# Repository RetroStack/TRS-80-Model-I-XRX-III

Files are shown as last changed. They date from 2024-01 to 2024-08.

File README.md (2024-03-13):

# TRS-80 Model 1 XRX-III Mod

This project faithfully reimplements the small brown mod board often seen attached to the keyboard of an TRS-80 Model 1. It corrects a software bug in earlier versions of the Level II ROMs, a bug later fixed in version 1.3. The design replicates the original mod's functionality using a 1-to-1 PCB design, including components, interfaces, and even traces.

Since this mod is no longer required for the latest ROM version, there's no need to create it. If you have an older computer, simply update the ROMs, and this mod becomes unnecessary. This repository serves more as a historical record and recreation of the board rather than for implementation.

For more details about this mod, visit: http://www.trs-80.org/xrx-modification/

The entire project is available under the MIT license.

## Project Details

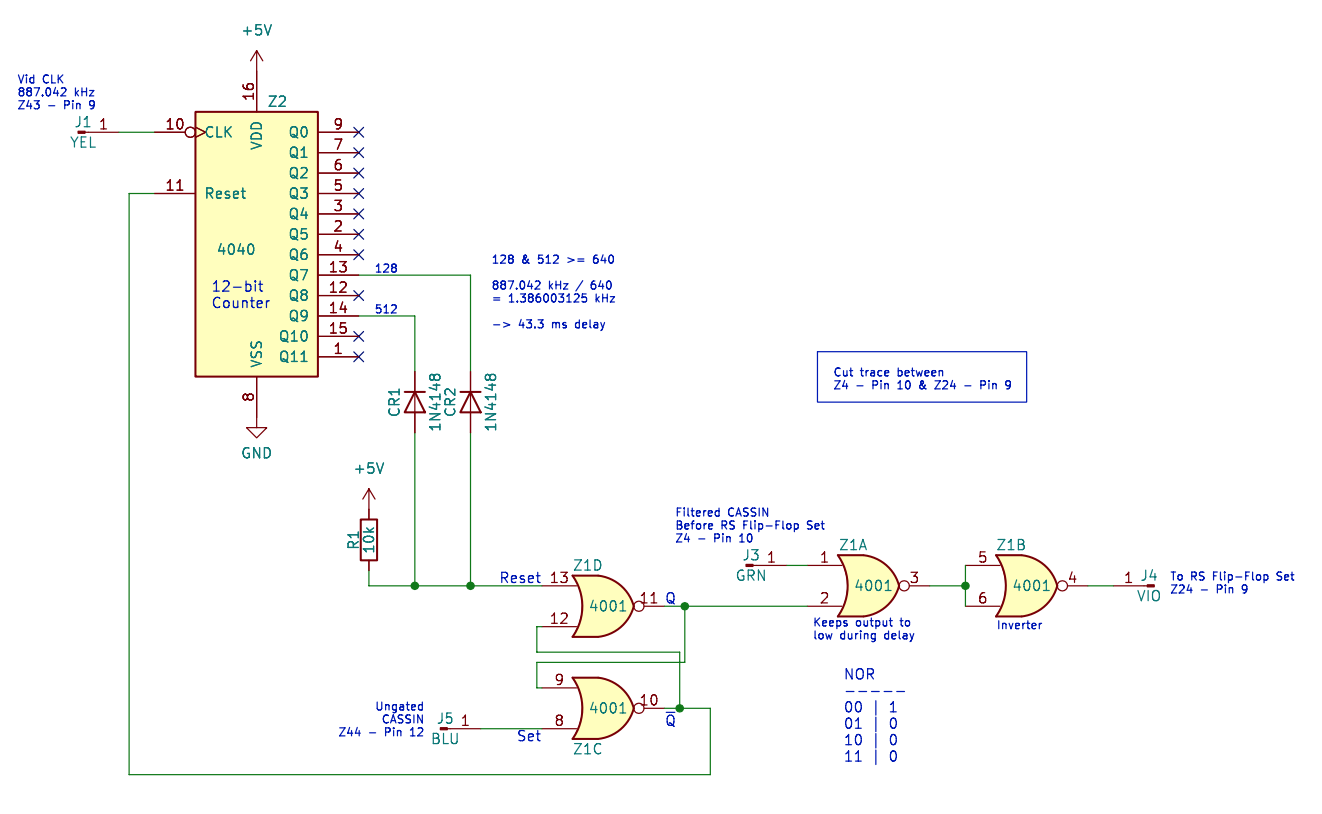
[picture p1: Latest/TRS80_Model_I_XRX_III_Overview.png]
Overview


### Latest Files

In the "Latest" folder, you'll find the most up-to-date design files, including:
- 3D views of the board
- The full schematics

### Implementation

This board has been implemented using KiCAD 7. The KiCAD project files are included in this repository.

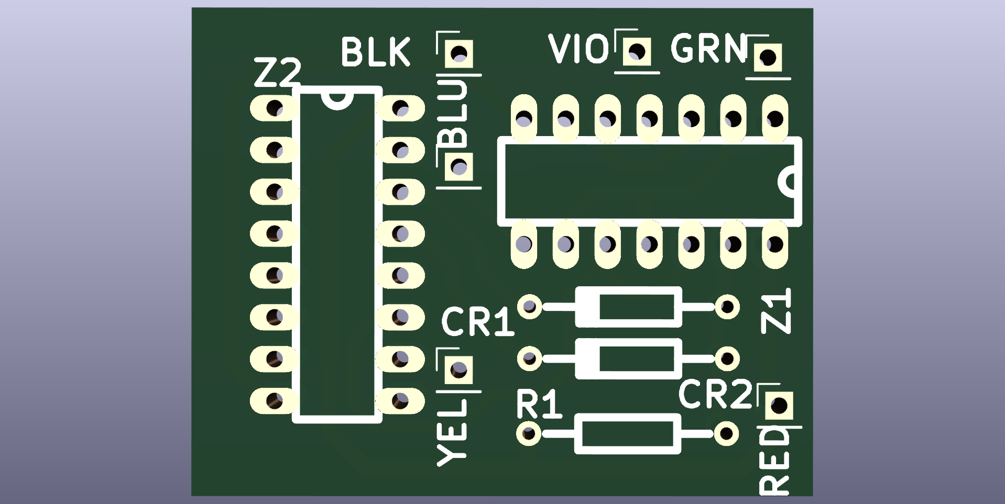
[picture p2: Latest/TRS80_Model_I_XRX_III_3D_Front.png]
Front

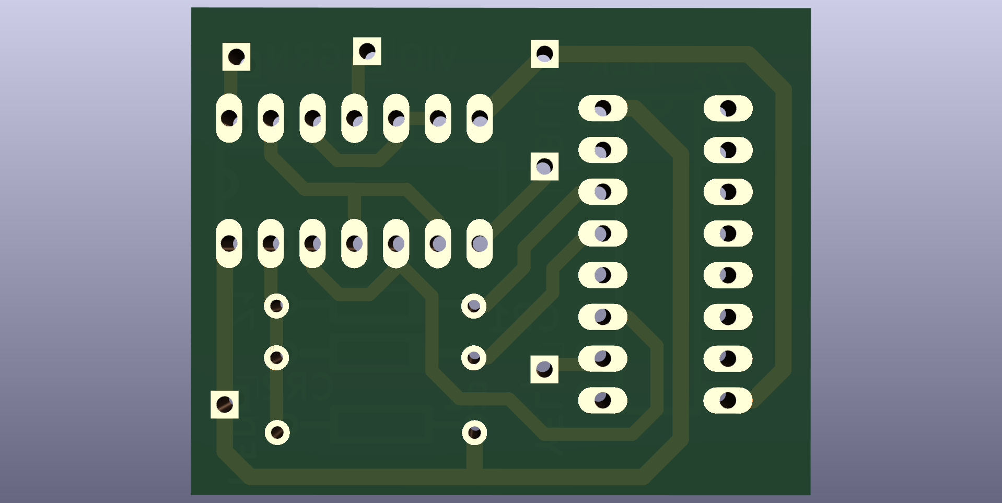
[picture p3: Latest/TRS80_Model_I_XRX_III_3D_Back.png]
Back


### Schematic Details

The mod monitors when the cassette-interface-in flip-flop on the main board resets. Upon this event, it performs two actions:
1) it removes the clear from the 12-bit counter on the mod board, and
2) it sets a flip-flop to prevent the signal from the OpAmps from reaching the mainboard flip-flop for the cassette data-in.

The counter, utilizing a clock from the video circuitry, counts until 43.3ms have elapsed, after which it resets the mod flip-flop and reopens the cassette data-in port. This process helps to avoid noise being accidentally picked up by the software, which was listening too early (a bug in early system ROM versions).

The board employs two NOR gates for the flip-flop and uses the other two NOR gates to gate the CASSIN signal and then to invert its value (since the gating also inverts the data, restoring the original state of CASSIN). 

Another noteworthy aspect is the use of the two diodes and the pull-up resistor, configured to function like an AND gate. Opting for diodes and a resistor was likely a more cost-effective solution than adding another IC.

### RetroStack Libraries

To work with this KiCAD project, you'll need the RetroStack libraries for KiCAD. Please [follow this link](https://www.github.com/RetroStack/KiCAD-Libraries) to access and install these libraries.

## Main TRS-80 Model 1 Repository

For additional resources related to the TRS-80 Model 1, be sure to check out the [central page for the TRS-80 Model 1](https://www.github.com/RetroStack/TRS-80-Model-I) on [RetroStack](https://www.github.com/RetroStack).

## Support this Project

RetroStack is dedicated to learning about older computer systems and creating documentation and videos about them. We are also resurrecting older computer systems by reimplementing them and making replacement parts available for free. If you're interested in supporting this project, consider visiting our [Patreon page](https://www.patreon.com/RetroStack). Your support is greatly appreciated!

## License

This project is licensed under the MIT License - see the [LICENSE](LICENSE) file for details.

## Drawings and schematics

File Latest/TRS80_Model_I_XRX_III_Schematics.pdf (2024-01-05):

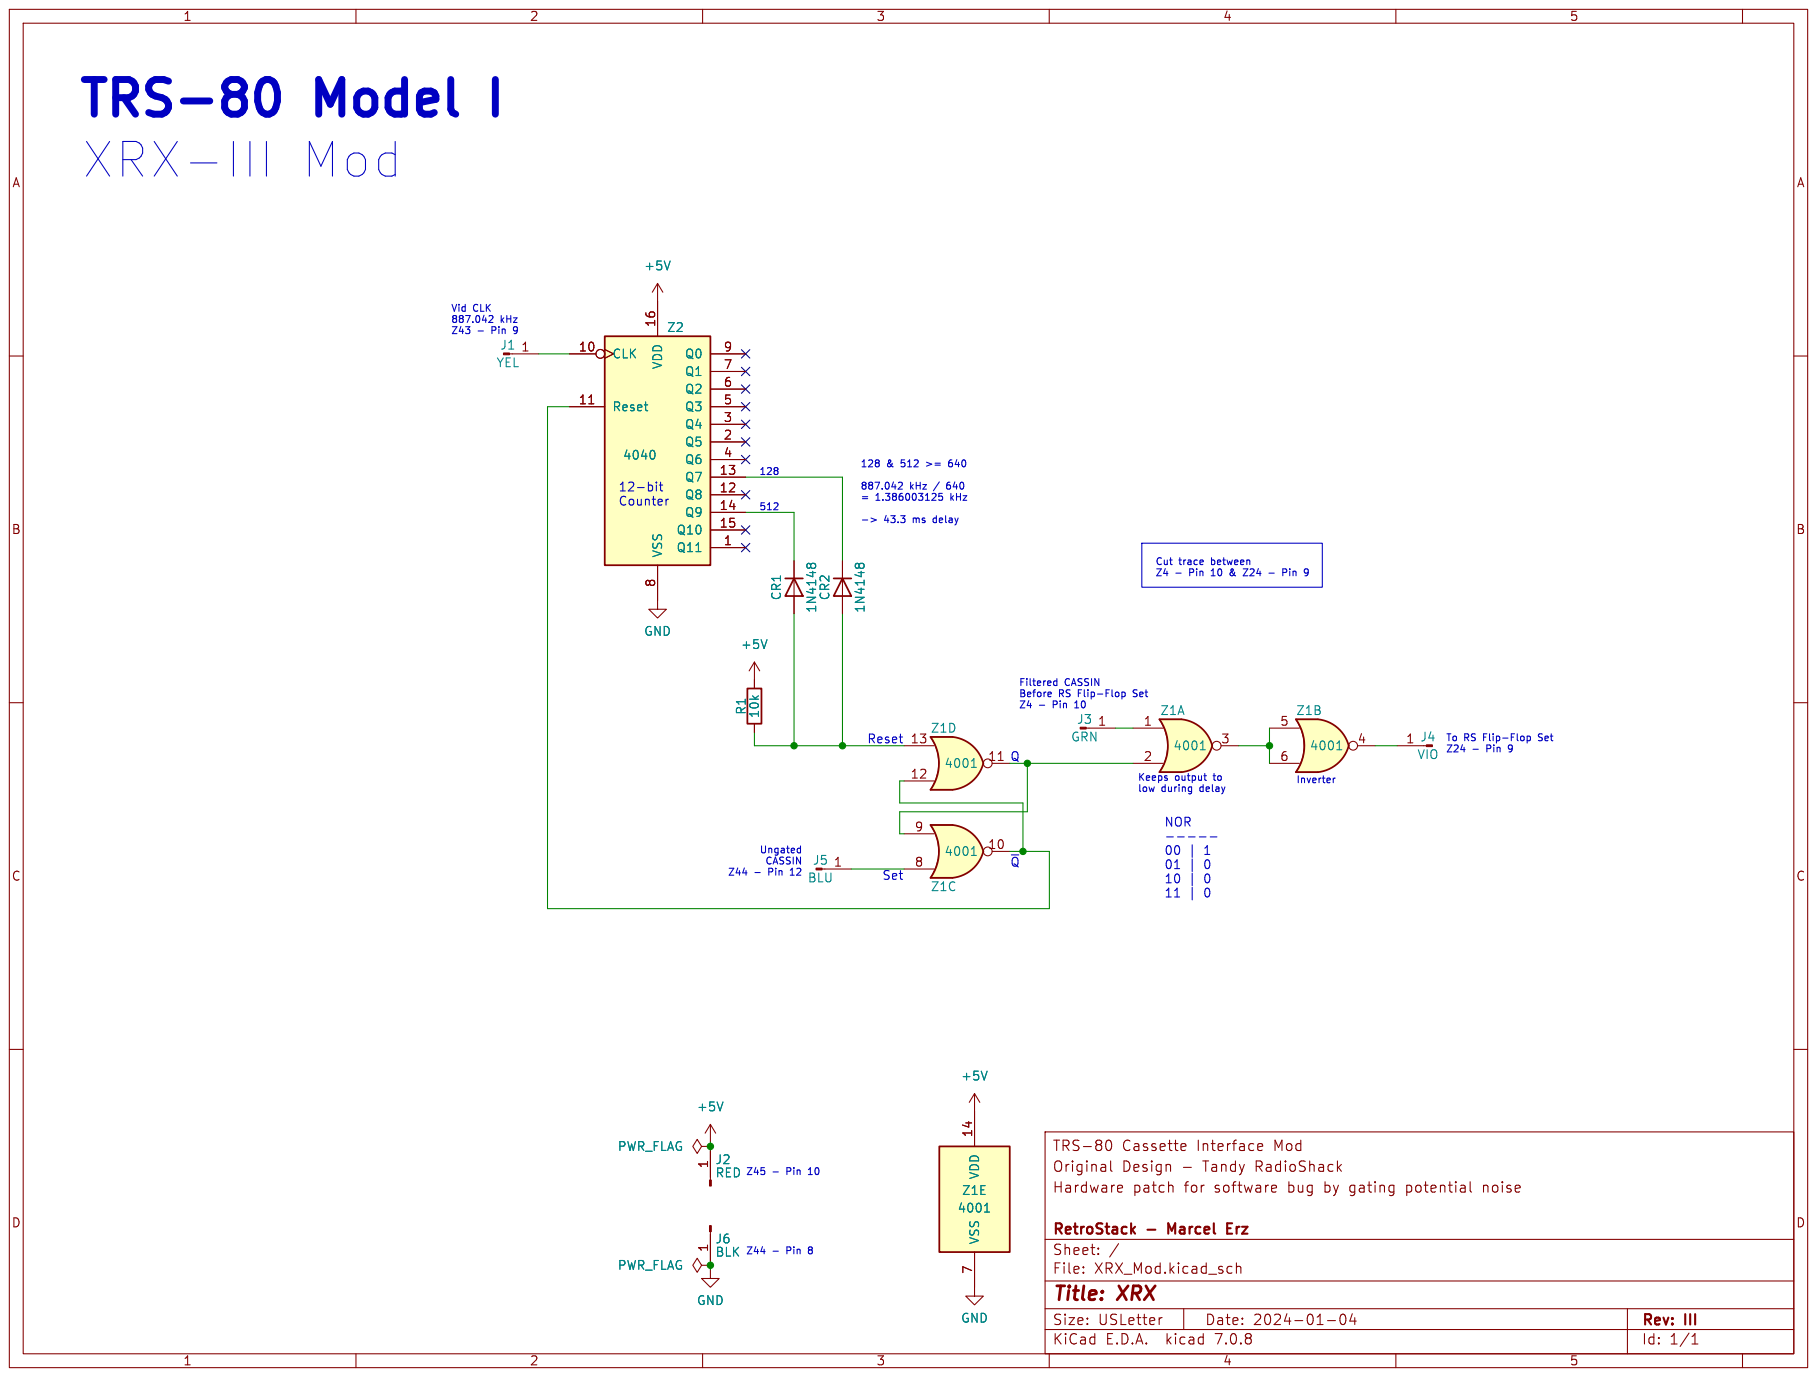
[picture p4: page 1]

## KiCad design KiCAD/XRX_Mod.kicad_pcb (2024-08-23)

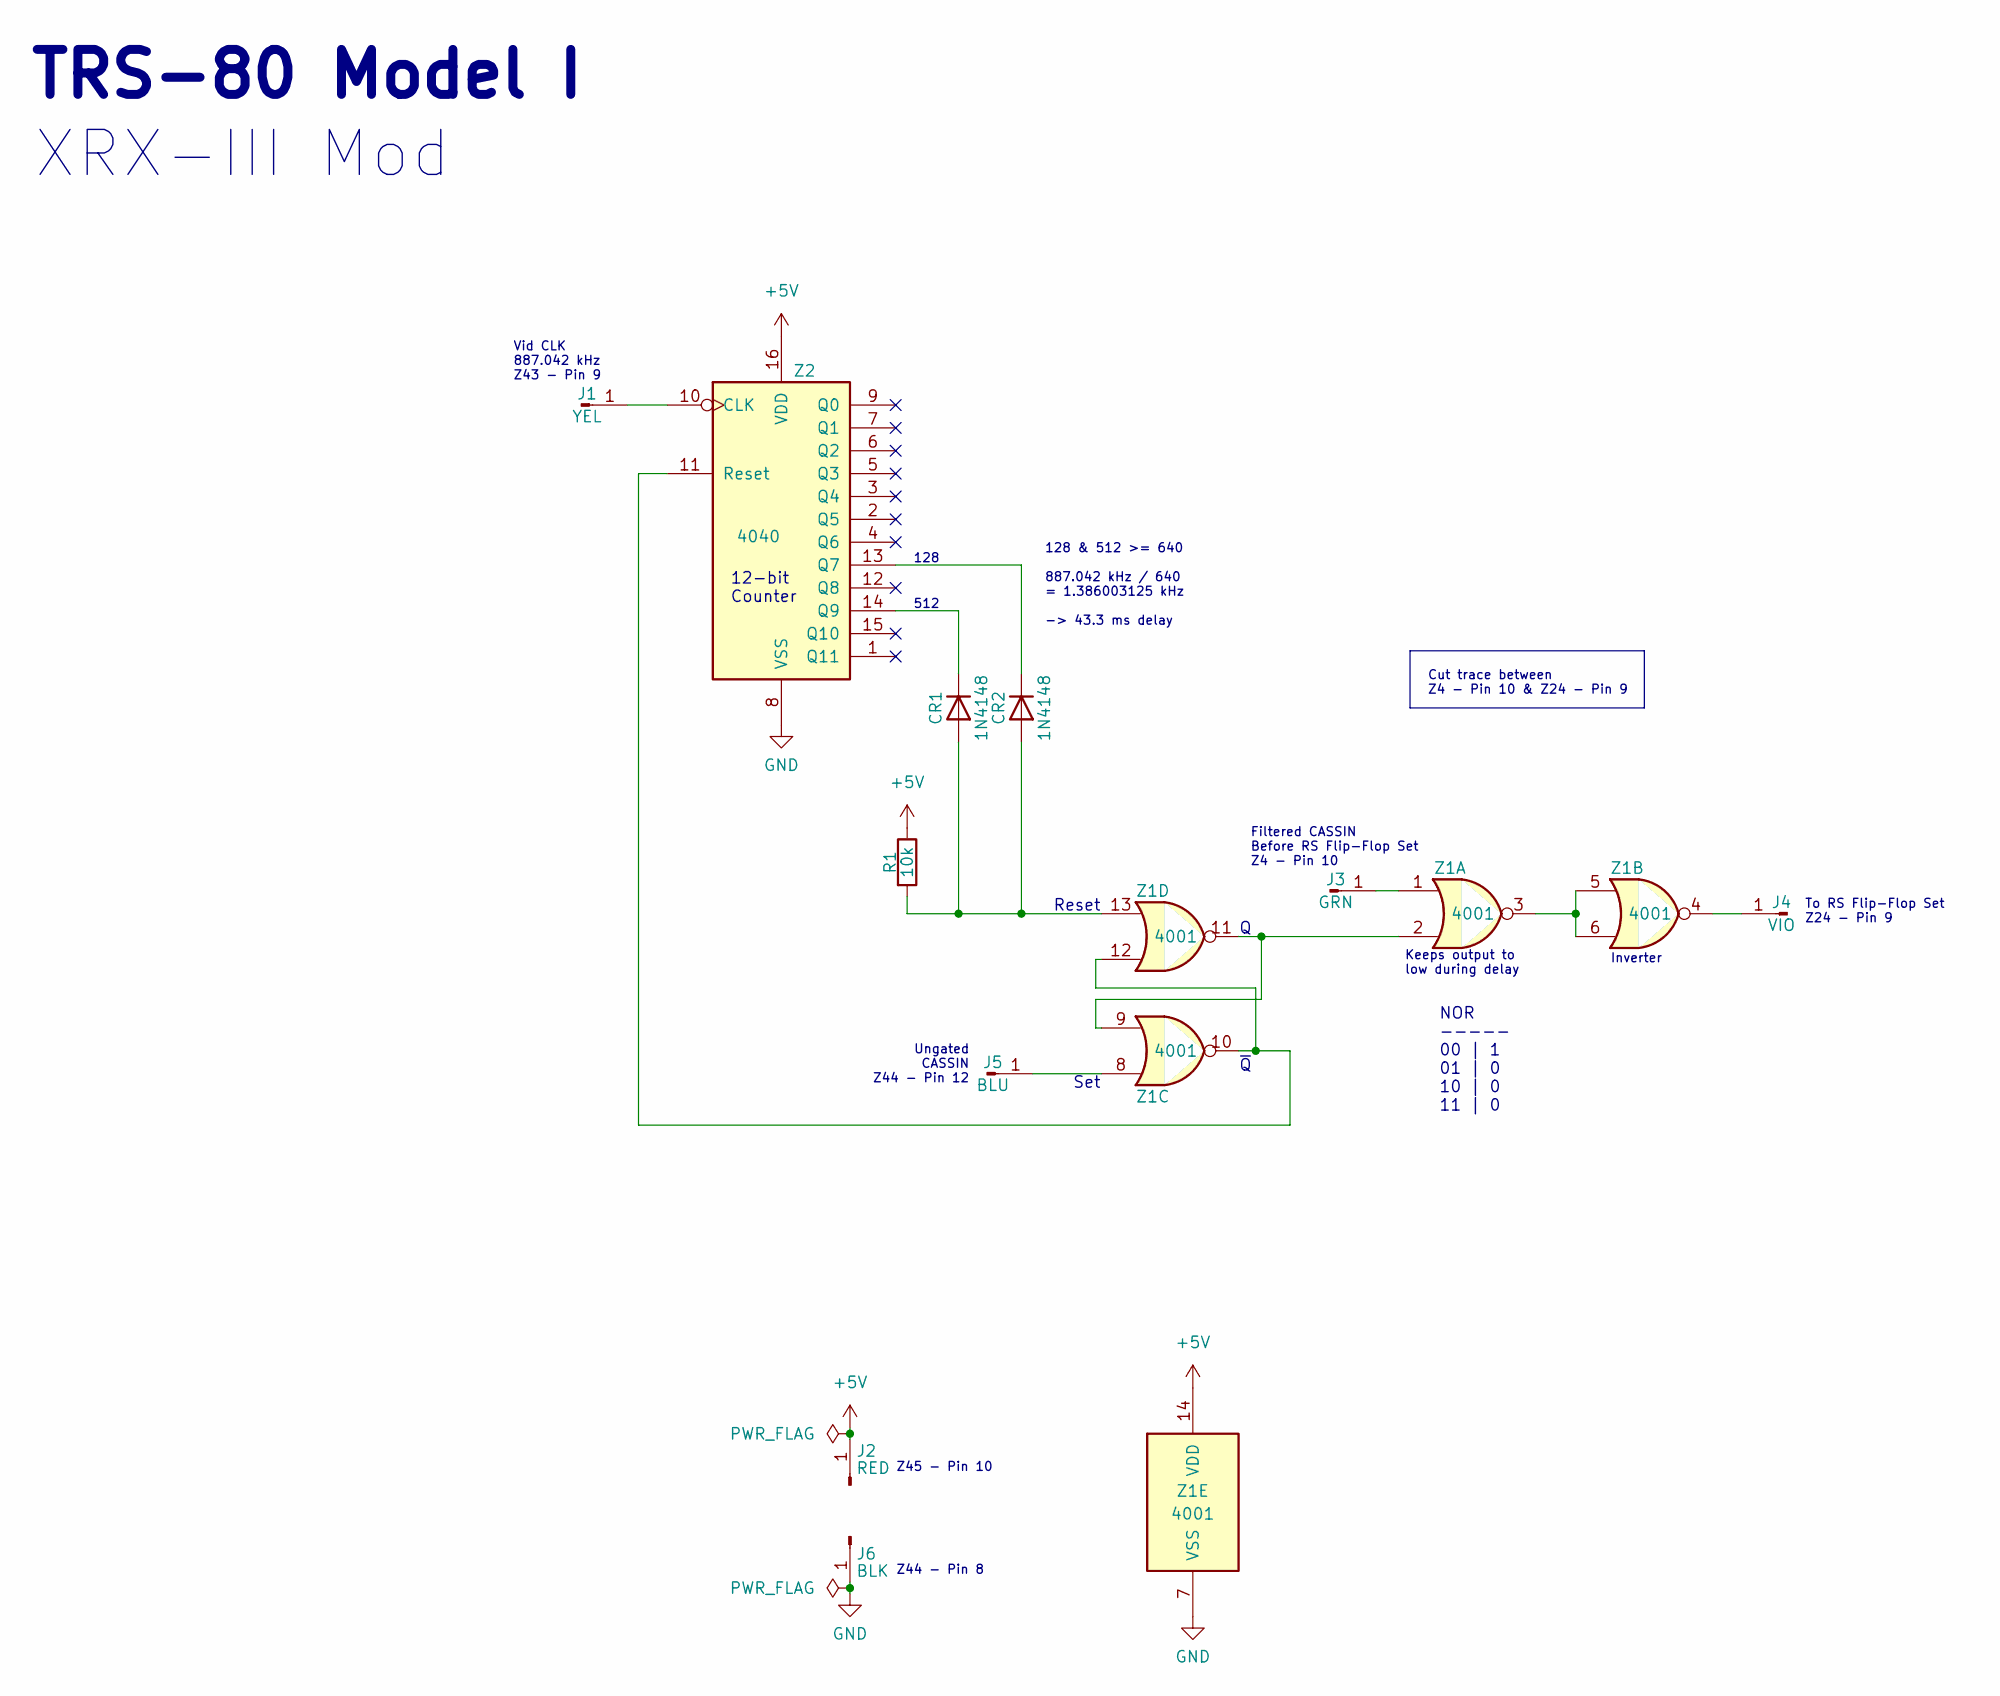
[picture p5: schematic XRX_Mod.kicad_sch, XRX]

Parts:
CR1, CR2: 1N4148; TRS80_Model_I_D
J1: YEL; PinHeader_1x01_P2.54mm_Vertical
J2: RED; PinHeader_1x01_P2.54mm_Vertical
J3: GRN; PinHeader_1x01_P2.54mm_Vertical
J4: VIO; PinHeader_1x01_P2.54mm_Vertical
J5: BLU; PinHeader_1x01_P2.54mm_Vertical
J6: BLK; PinHeader_1x01_P2.54mm_Vertical
R1: 10k; TRS80_Model_I_R_0.25W
Z1: 4001; TRS80_Model_I_DIP14
Z2: 4040; TRS80_Model_I_DIP16

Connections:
+5V: J2.1, R1.1, Z1.14 (VDD), Z2.16 (VDD)
GND: J6.1, Z1.7 (VSS), Z2.8 (VSS)
unnamed: CR1.2 (A), CR2.2 (A), R1.2, Z1.13
unnamed: CR1.1 (K), Z2.14 (Q9)
unnamed: CR2.1 (K), Z2.13 (Q7)
unnamed: J1.1, Z2.10 (CLK)
unnamed: J3.1, Z1.1
unnamed: J4.1, Z1.4
unnamed: J5.1, Z1.8
unnamed: Z1.3, Z1.5, Z1.6
unnamed: Z1.2, Z1.9, Z1.11
unnamed: Z1.10, Z1.12, Z2.11 (Reset)

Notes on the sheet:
Reset
TRS-80 Model I
Vid CLK 887.042 kHz Z43 - Pin 9
128
Cut trace between Z4 - Pin 10 & Z24 - Pin 9
To RS Flip-Flop Set Z24 - Pin 9
12-bit Counter
Filtered CASSIN Before RS Flip-Flop Set Z4 - Pin 10
Ungated CASSIN Z44 - Pin 12
Set
Keeps output to low during delay
Z44 - Pin 8
Inverter
NOR ----- 00 | 1 01 | 0 10 | 0 11 | 0
Z45 - Pin 10
128 & 512 >= 640 887.042 kHz / 640 = 1.386003125 kHz -> 43.3 ms delay
~{Q}
XRX-III Mod
512

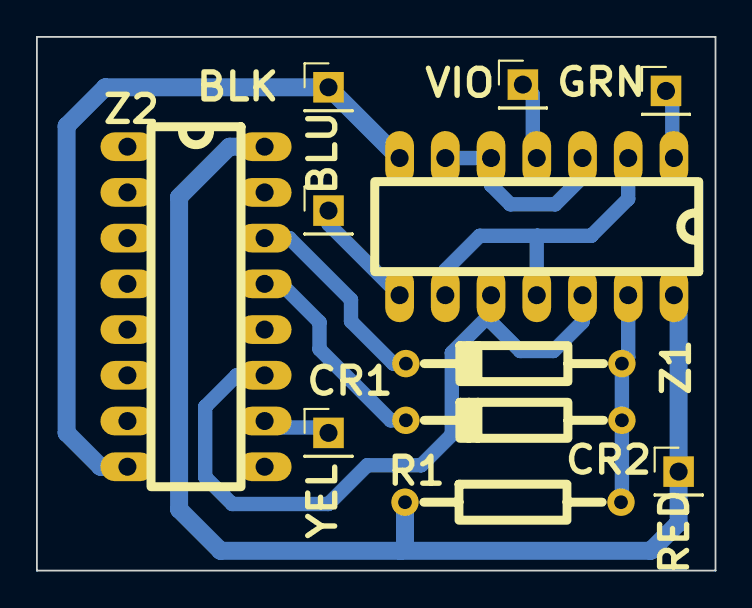
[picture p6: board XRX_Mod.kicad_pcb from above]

Board: 2 copper layers, 37.7 x 29.7 mm, 11 parts (0 on the bottom side), 12 nets.

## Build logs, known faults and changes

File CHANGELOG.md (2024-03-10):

# TRS-80 Model 1 XRX-II Mod - Changelog

## Versioning

I've devised a versioning system for my replica projects. This system provides clarity about each of my version's significance. My version identifier consistently follows the original revision details, allowing for a clear distinction between the original manufacturer's revision and my own.

Here's the format for the versioning:
- The initial character is always an "E," representing my last name. This choice ensures that others can adopt the same versioning style if needed.
- The following character is a number, with "1" signifying a 1-1 re-implementation of the original. Numbers beyond "1" denote various board variations, such as new designs features, more modern components, or different interface ports.
- The final character represents my actual revision of that board. Using a character for this purpose distinguishes it from the re-implementation type mentioned above, and it allows for up to 26 revisions to refine the project.

## 5th Jan 2024 - E1A

Completed, but untested.

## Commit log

2024-01-14 Cleanup folders
    [XRX_Mod.kicad_pcb, XRX_Mod.kicad_sch]
2024-08-23 Adding gerbers for JLCPCB only
    [XRX_Mod.kicad_pcb]
